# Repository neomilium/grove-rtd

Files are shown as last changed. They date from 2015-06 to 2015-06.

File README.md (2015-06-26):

# grove-rtd
Precision temperature (RTD) circuit based on application note from Microchip: "AN687 - Precision Temperature - Sensing With RTD Circuits".

Scheme and BOM are designed to use PT100 (2 or 3 wires) with a 0-5 volts output range.

PCB can be used with various probe types and different output range, please look at the application note.

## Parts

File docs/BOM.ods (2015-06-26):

N° | PARTS | DESCRIPTION | QTE | QTE x3 | QTE x4 | OBSERVATION | VALEUR | BOITIER | FABRICANT | REF. FABRICANT | DISTRIBUTEUR | CODE CDE DISTRIBUTEUR | UDV | DISPO | PRIX / UDV | QTE UDV | PRIX
 | R12, R14 | RESISTANCE | 2 | 6 | 8 | 1% 125mW 150V 100ppm/°C | 1K | 0805 | VISHAY | CRCW08051K00FKEA | FARNELL | 1469847 | 50min | OK | 0,021 € | 50 | 1,050 € | 50 | 1,050 €
 | R15 | RESISTANCE | 1 | 3 | 4 | 1% 125mW 150V 100ppm/°C | 1K1 | 0805 | VISHAY | CRCW08051K10FKEA | FARNELL | 1469849 | 50min | OK | 0,021 € | 50 | 1,050 € | 50 | 1,050 €
 | RREF1 | RESISTANCE | 1 | 3 | 4 | 0,1% 100mW 200V | 1K | 0805 | TE CONNECTIVITY / NEOHM | CPF0805B1K0E1 | FARNELL | 1697431 | 10min | OK | 0,420 € | 10 | 4,200 € | 10 | 4,200 €
 | RREF2 | RESISTANCE | 1 | 3 | 4 | 0,1% 100mW 200V | 1,5K | 0805 | TE CONNECTIVITY / NEOHM | CPF0805B1K5E1 | FARNELL | 1697434 | 10min | OK | 0,420 € | 10 | 4,200 € | 10 | 4,200 €
 | R10 | RESISTANCE | 1 | 3 | 4 | 0,1% 100mW 100V 25ppm/°C | 3,09K | 0805 | WELWYN | PCF0805R-3K09BT1 | FARNELL | 1353269 | 1 | OK | 0,550 € | 3 | 1,650 € | 4 | 2,200 €
 | R8 | RESISTANCE | 1 | 3 | 4 | 0,1% 100mW 100V 25ppm/°C | 17,4K | 0805 | WELWYN | PCF0805R-17K4BT1 | FARNELL | 1353223 | 1 | OK | 0,550 € | 3 | 1,650 € | 4 | 2,200 €
 | R11 | RESISTANCE | 1 | 3 | 4 | 1% 125mW 150V 100ppm/°C | 20K | 0805 | VISHAY | CRCW080520K0FKEA | FARNELL | 1469893 | 50min | OK | 0,021 € | 50 | 1,050 € | 50 | 1,050 €
 | R1, R2, R3, R4 | RESISTANCE | 4 | 12 | 16 | 0,1% 100mW 100V 25ppm/°C | 27K | 0805 | SUSUMU | RR1220P-273-B-T5 | FARNELL | 1653303 | 1 | OK | 0,104 € | 12 | 1,248 € | 16 | 1,664 €
 | R7 | RESISTANCE | 1 | 3 | 4 | 1% 125mW 150V 100ppm/°C | 49,9K | 0805 | VISHAY | CRCW080549K9FKEA | FARNELL | 1469934 | 50min | OK | 0,021 € | 50 | 1,050 € | 50 | 1,050 €
 | C8A | CONDENSATEUR | 1 | 3 | 4 | Y5V 25V | 68n | 0805 | MULTICOMP | MCCA000293 | FARNELL | 1759163 | 100min | OK | 0,010 € | 100 | 1,000 € | 100 | 1,000 €
 | R13 | RESISTANCE | 1 | 3 | 4 | 1% 100mW 100V 100ppm/°C | 82 | 0805 | WELWYN | WCR0805-82RFI | FARNELL | 1100307 | 50min | OK | 0,026 € | 50 | 1,300 € | 50 | 1,300 €
 | R5, R6 | RESISTANCE | 2 | 6 | 8 | 1% 125mW 150V 100ppm/°C | 100K | 0805 | VISHAY | CRCW0805100KFKEA | FARNELL | 1469860 | 50min | OK | 0,021 € | 50 | 1,050 € | 50 | 1,050 €
 | C1 | CONDENSATEUR | 1 | 3 | 4 | X7R 50V 10% | 100n | 0805 | MULTICOMP | MCCA000386 | FARNELL | 1759265 | 100min | OK | 0,011 € | 100 | 1,100 € | 100 | 1,100 €
 | R9 | RESISTANCE | 1 | 3 | 4 | 0,1% 100mW 100V 25ppm/°C | 107K | 0805 | MULTICOMP | MCTC0525B1073T5E | FARNELL | 1576017 | 5min | OK | 0,700 € | 5 | 3,500 € | 5 | 3,500 €
 | R16 | RESISTANCE | 1 | 3 | 4 | 1% 100mW 150V 100ppm/°C | 118 | 0805 | MULTICOMP | MC 0.1W 0805 1% 110R | FARNELL | 9332430 | 50min | OK | 0,046 € | 50 | 2,300 € | 5 | 0,230 €
 | C9 | CONDENSATEUR | 1 | 3 | 4 | X7R 16V 10% | 180n | 0805 | MULTICOMP | MCCA000279 | FARNELL | 1759148 | 100min | OK | 0,023 € | 100 | 2,300 € | 100 | 2,300 €
 | C8B | CONDENSATEUR | 1 | 3 | 4 | X7R 16V 10% | 390n | 0805 | MULTICOMP | MCCA000285 | FARNELL | 1759155 | 100min | OK | 0,027 € | 100 | 2,700 € | 100 | 2,700 €
 | U1 | IC, OP AMP, 2.5V, QUAD | 1 | 3 | 4 |  |  | SOIC | MICROHIP | MCP609-I/SL | FARNELL | 1292248 | 1 | OK | 1,620 € | 3 | 4,860 € | 4 | 6,480 €
 | X1 | CONNECTEUR | 1 | 3 | 4 | MKDSN1,5/3-5,08 | RTD |  | PHOENIX | 1729131 | FARNELL | 3041451 | 1 | OK | 1,390 € | 3 | 4,170 € | 4 | 5,560 €
 | J1 | CONNECTEUR | 1 | 3 | 4 |  | RTD_SIG |  |  | TWIG_2.0-DIP-FEMALE |  |  |  |  |  |  | 0 |  | 0
 | DZ1 | REGULATEUR AJUSTABLE CMS | 2 | 6 | 8 |  |  |  | TEXAS INSTRUMENTS | TLVH431BIDBZTG4 | FARNELL | 1053318 | 1 | OK | 0,680 € | 6 | 4,080 € | 8 | 5,440 €
 |  |  |  |  |  |  |  |  |  |  |  |  |  |  |  |  | 13,3
 |  |  |  |  |  |  |  |  |  |  |  |  |  |  |  |  | 58,808 € |  | 49,324 €

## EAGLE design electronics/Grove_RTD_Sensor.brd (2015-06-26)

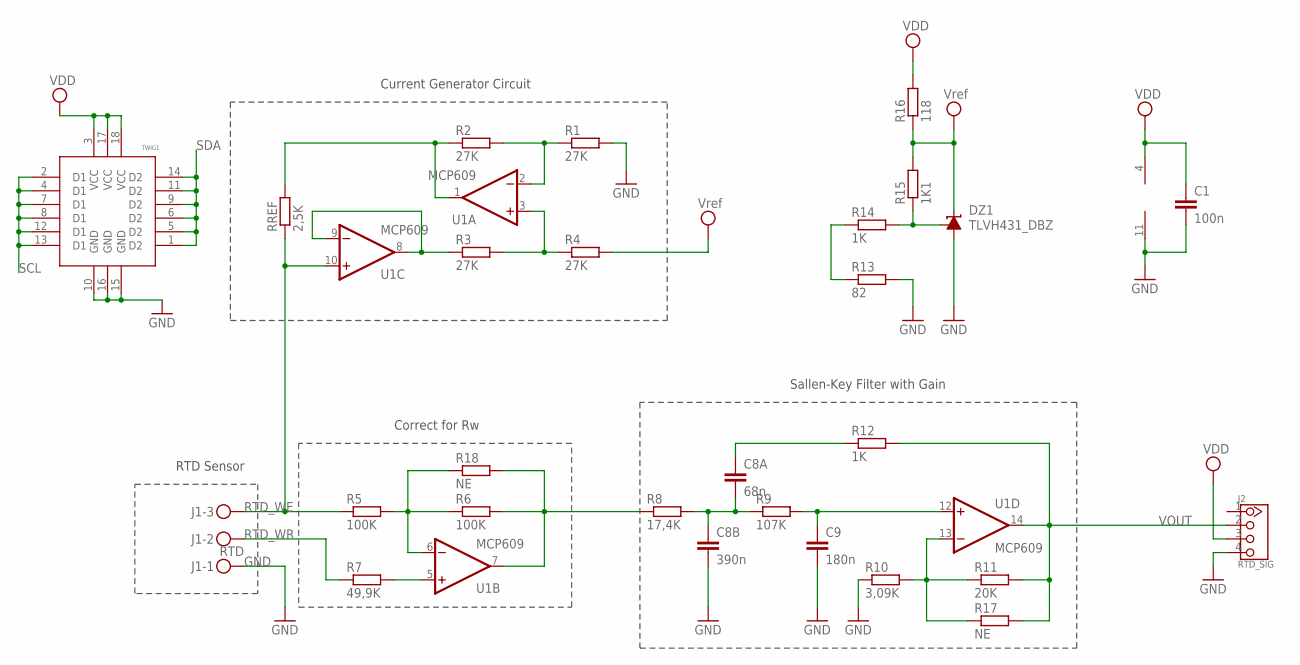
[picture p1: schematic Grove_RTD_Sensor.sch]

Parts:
C1: 100n; C0805
C8A: 68n; C0805
C8B: 390n; C0805
C9: 180n; C0805
DZ1: TLVH431_DBZ; SOT23
J1: RTD; MKDSN1,5/3-5,08
J2: RTD_SIG; 2.0_1X4
R1, R2, R3, R4: 27K; R0805
R5, R6: 100K; R0805
R7: 49,9K; R0805
R8: 17,4K; R0805
R9: 107K; R0805
R10: 3,09K; R0805
R11: 20K; R0805
R12, R14: 1K; R0805
R13: 82; R0805
R15: 1K1; R0805
R16: 118; R0805
R17, R18: NE; R0805
RREF: 2,5K; R0805
TWIG1: TWIG-U2'HOLES'; U2_HOLES
U1: MCP609; SO14

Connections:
GND: C1.2, C8B.2, C9.2, DZ1.3 (A), J1.1, J2.4, R1.2, R10.1, R13.2, TWIG1.10 (GND), TWIG1.15 (GND), TWIG1.16 (GND), U1.11 (V-)
unnamed: R1.1, R2.2, U1.2 (-IN)
unnamed: R3.2, R4.1, U1.3 (+IN)
unnamed: R2.1, RREF.2, U1.1 (OUT)
unnamed: R3.1, U1.8 (OUT), U1.9 (-IN)
unnamed: DZ1.1 (FB), R14.2, R15.1
unnamed: R6.2, R8.1, R18.2, U1.7 (OUT)
unnamed: R7.2, U1.5 (+IN)
unnamed: R5.2, R6.1, R18.1, U1.6 (-IN)
unnamed: R13.1, R14.1
unnamed: C9.1, R9.2, U1.12 (+IN)
unnamed: C8A.2, C8B.1, R8.2, R9.1
unnamed: R10.2, R11.1, R17.1, U1.13 (-IN)
unnamed: C8A.1, R12.1
RTD_WE: J1.3, R5.1, RREF.1, U1.10 (+IN)
RTD_WR: J1.2, R7.1
SCL: TWIG1.2 (D1), TWIG1.4 (D1), TWIG1.7 (D1), TWIG1.8 (D1), TWIG1.12 (D1), TWIG1.13 (D1)
SDA: TWIG1.1 (D2), TWIG1.5 (D2), TWIG1.6 (D2), TWIG1.9 (D2), TWIG1.11 (D2), TWIG1.14 (D2)
VDD: C1.1, J2.3, R16.2, TWIG1.3 (VCC), TWIG1.17 (VCC), TWIG1.18 (VCC), U1.4 (V+)
VEE: DZ1.2 (C), R4.2, R15.2, R16.1
VOUT: J2.2, R11.2, R12.2, R17.2, U1.14 (OUT)

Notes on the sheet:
Current Generator Circuit
RTD Sensor
Correct for Rw
Sallen-Key Filter with Gain

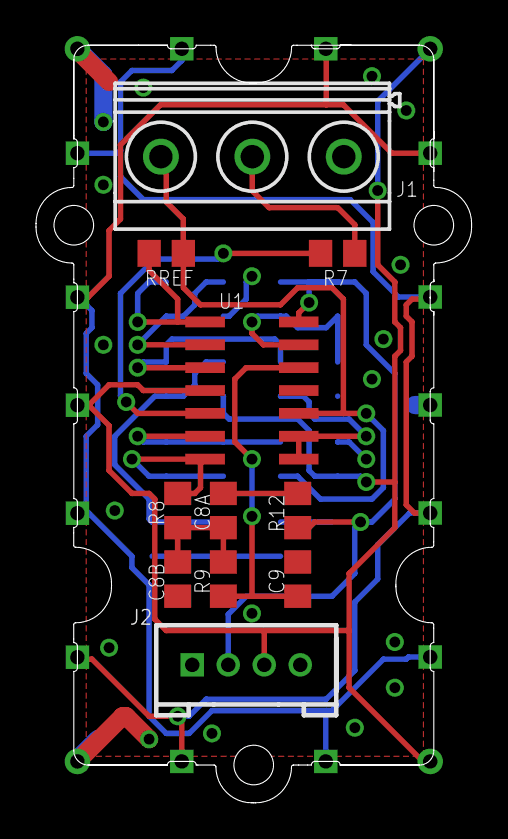
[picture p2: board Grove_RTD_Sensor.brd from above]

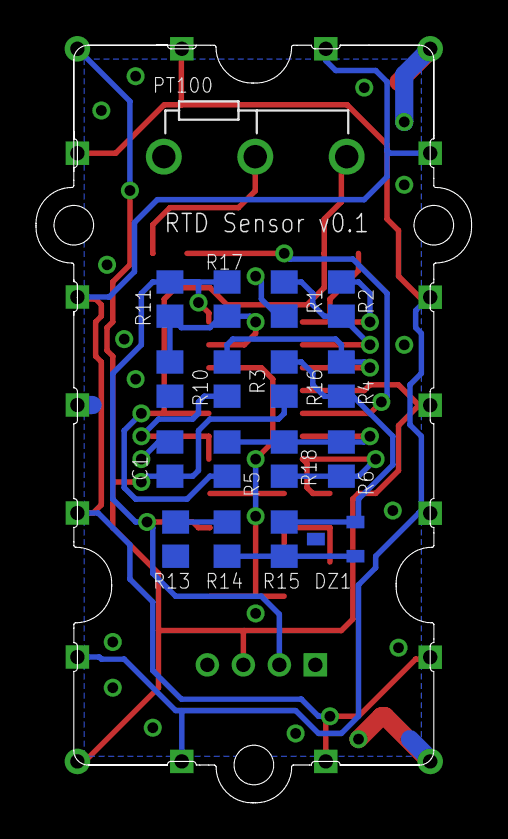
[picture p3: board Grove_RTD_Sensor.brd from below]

Board: 2 copper layers, 24.2 x 42.1 mm, 28 parts (16 on the bottom side), 21 nets.
